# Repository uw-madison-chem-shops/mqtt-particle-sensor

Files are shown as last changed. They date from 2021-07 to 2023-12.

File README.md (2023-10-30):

# MQTT particle sensor

Designed to work with [mqtt.chem.wisc.edu](https://mqtt.chem.wisc.edu/).

## Repository

This is an open source hardware project licensed under the CERN Open Hardware Licence Version 2 - Permissive.
Please see the LICENSE file for the complete license.

## PCB

This PCB was designed using KiCAD version 7.
Refer to `mqtt_particle_sensor.pdf` for schematic.
PCB images generated with [tracespace](https://github.com/tracespace/tracespace) follow.




## Bill of Materials

| reference | value | manufacturer | part number | price | vendors |
| :--- | :--- | :--- | :--- | :---- | :--- |
| C1 | 1u | Multicomp | MC1206B105K500CT  | $0.10 | [Newark](https://www.newark.com/multicomp-pro/mc1206b105k500ct/ceramic-capacitor-1uf-50v-x7r/dp/06R4217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) |
| C2 | 1u |  Multicomp | MC1206B105K500CT  | $0.10 | [Newark](https://www.newark.com/multicomp-pro/mc1206b105k500ct/ceramic-capacitor-1uf-50v-x7r/dp/06R4217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) |
| C3 | 100u | Illinois Capacitor|  107KXM025M| $0.25| [Newark](https://www.newark.com/cornell-dubilier/107kxm025m/aluminum-electrolytic-capacitor/dp/69K8200?ost=107kxm025m) |
| C4 | 10u |  Yageo | CC1206KKX7R8BB106 | $0.25 | [Newark](https://www.newark.com/yageo/cc1206kkx7r8bb106/cap-10uf-25v-mlcc-1206-rohs-compliant/dp/26AK2052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) |
| C5 | 22u | Murata Electronics| GRM31CC71C226ME11L| $0.75 | [Newark](https://www.newark.com/murata/grm31cc71c226me11l/cap-22uf-16v-mlcc-1206-rohs-compliant/dp/64AJ4421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) |
| R1 | 470k | 1206 1/4 1%  | | | |
| R2 | 1M | 1206 1/4 1%  | | | |
| R3 | 1M | 1206 1/4 1%  | | | |
| R4 | 4.7k | 1206 1/4 1%  | | | |
| R5 | 4.7k | 1206 1/4 1%  | | | |
| R6 | 1k | 1206 1/4 1%  | | | |
| R7 | 1k | 1206 1/4 1%  | | | |
| R8 | 4.7k | 1206 1/4 1%  | | | |
| R9 | 4.7k | 1206 1/4 1%  | | | |
| A1 | ESP8266 HUZZAH BREAKOUT BOARD | Adafruit | 2471 |  $10.00 | [Newark](https://www.newark.com/adafruit/2471/adafruit-huzzah-esp8266-breakout/dp/98Y0121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) |
| U1 | Auto Reset Timer | Nexperia  | HEF4060BT,653 | $0.50 |[Newark](https://www.newark.com/nexperia/hef4060bt-653/ic-4000-locmos-smd-4060-soic16/dp/25M9620?st=hef4060bt,653) |
| U2 | ATtiny85 | Microchip Technology| ATTINY85-20PU| $3.00 | [Newark](https://www.newark.com/microchip/attiny85-20pu/microcontroller-mcu-8-bit-attiny/dp/68T3808?ost=attiny85-20pu)|
| U2 | 8pin Dip Socket | Millmax | 110-93-308-41-001000| $1.00 | [Newark](https://www.newark.com/mill-max/110-93-308-41-001000/dip-socket-8-position-through/dp/17C2295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)|
| U3 | HPM Particle Sensor | Honeywell  | 	HPMA115S0-XXX| $63.75 |  [Newark](https://www.newark.com/honeywell/hpma115s0-xxx/particle-sensor-laser-uart-5v/dp/24AC9030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) |
| U3 | Header Connector | Molex | 53047-0810 | $0.14 | [Newark](https://www.newark.com/molex/53047-0810/connector-header-8pos-1row-1-25mm/dp/98K9826?st=53047-0810)|
| U3 | 8pin ribbon cable | Molex | 151340801 | $10.06 | [Newark](https://www.newark.com/molex/15134-0801/cable-assy-8pos-rcpt-rcpt-100mm/dp/01AC7007?ost=151340801)|
| D1 | LED (red) |  Lite-On Inc. | LTST-C230KRKT | $0.25 | [Digikey](https://www.digikey.com/en/products/detail/liteon/LTST-C230KRKT/386857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) |
| D2 | LED (green) |  Lite-On Inc | LTST-C150KGKT| $0.25 | [Digikey](https://www.digikey.com/en/products/detail/liteon/LTST-C150KGKT/365085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) |
| PS1 | Power | CUI | VXO7805-500-M-TR | $3.00 |[Newark](https://www.newark.com/cui/vxo7805-500-m-tr/dc-dc-converter-fixed-5v-rohs/dp/13AJ1536?ost=vxo7805-500-m-tr) |
| J2 | Barrel Jack |CUI |  PJ-002A  | $1.00 | [Digikey](https://www.digikey.com/en/products/detail/cui-devices/PJ-002A/96962) |
| Q1 | 2N7000 | Diodes Inc.  | 2N7002K-7  |$0.25 |[Newark](https://www.newark.com/diodes-inc/2n7002k-7/mosfet-n-channel-60-v-800ma-sot/dp/25R5681?st=2n7002k-7) |
| Q2 | 2N7000 | Diodes Inc.  | 2N7002K-7  |$0.25 |[Newark](https://www.newark.com/diodes-inc/2n7002k-7/mosfet-n-channel-60-v-800ma-sot/dp/25R5681?st=2n7002k-7) |

## Firmware

This project uses [micropython](https://micropython.org/), specifically [microhomie](https://github.com/microhomie/microhomie).
Refer to the "firmware" directory in this repository for detailed instructions.

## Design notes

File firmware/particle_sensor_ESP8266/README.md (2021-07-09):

# mqtt-particle-sensor firmware

This project uses C with [Arduino IDE](https://www.arduino.cc/en/software/) and [micropython](https://micropython.org/), specifically [microhomie](https://github.com/microhomie/microhomie). Currently we build on microhomie-esp8266-v3.0.2, the binary is in the folder.

You must define the private information defined in `settings.py`. Copy `settings.py.example` to make a folder `settings.py` and define all relevant variables.

Run `flash.sh` to flash the board. You will need [esptool](https://github.com/espressif/esptool) and [ampy](https://github.com/scientifichackers/ampy).

We recommend an [FTDI Basic Breakout](https://www.sparkfun.com/products/9716) to physically program the ESP8266.

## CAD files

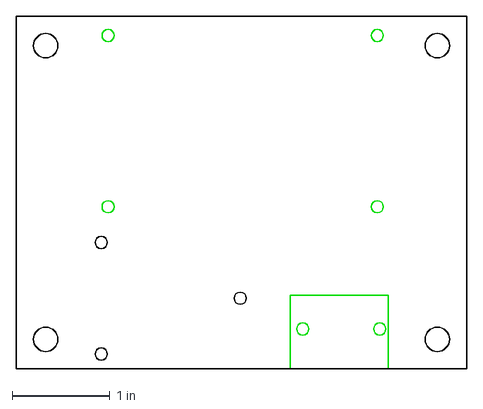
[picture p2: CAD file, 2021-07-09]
mounting-plate/particl-sensor-mounting-plate.dxf
4.60 x 3.60 in

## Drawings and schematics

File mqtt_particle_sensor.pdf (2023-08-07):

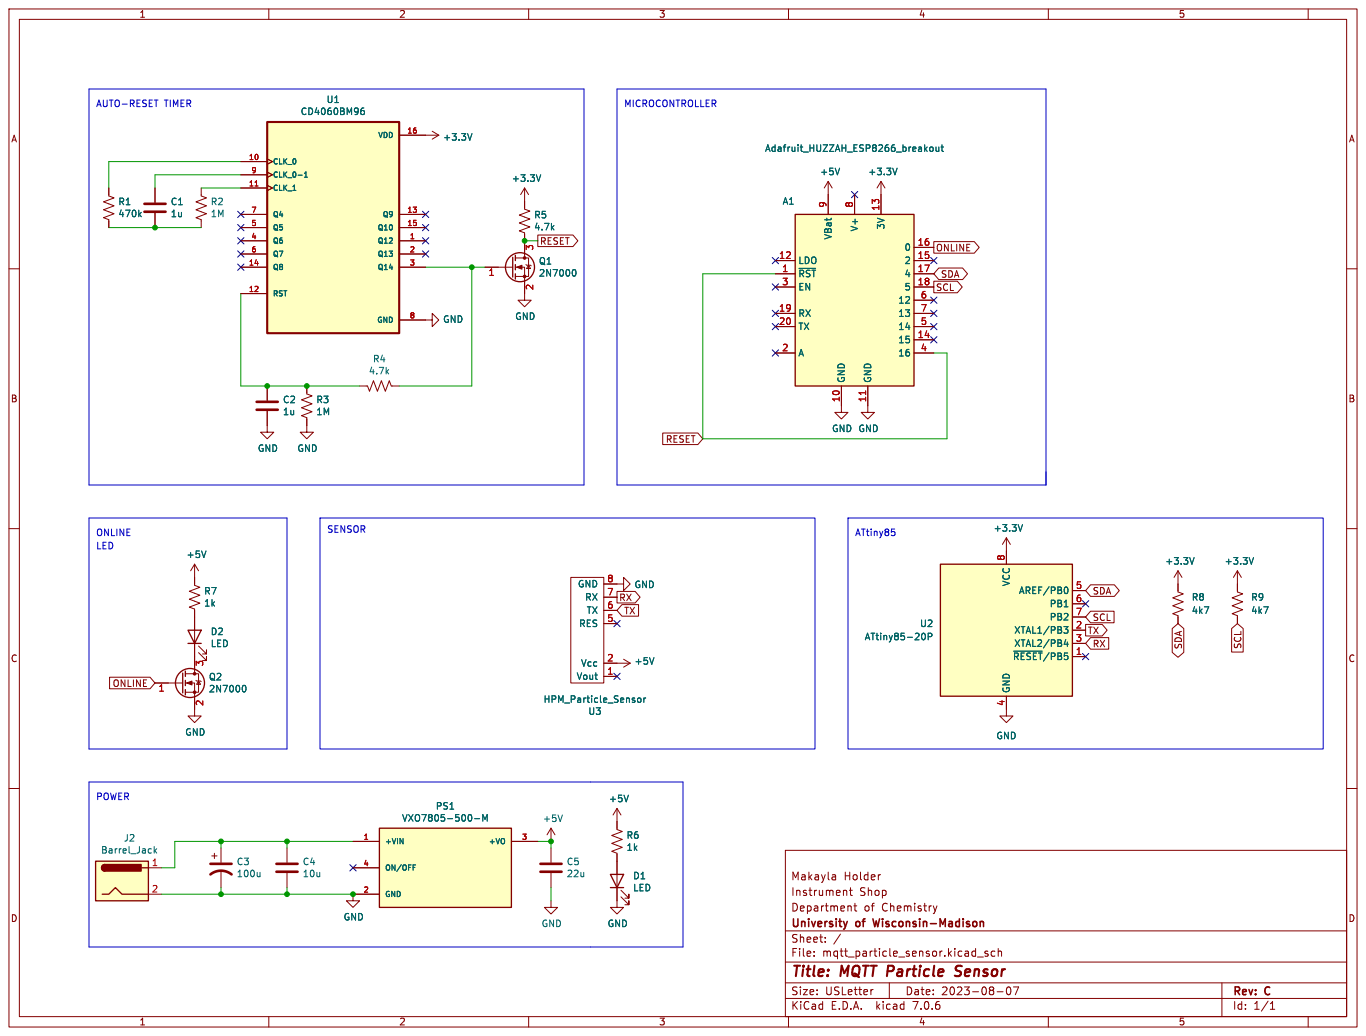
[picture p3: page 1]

Vout 1 Vcc 2 RES 5 TX 6 RX 7 GND 8 U3 HPM_Particle_SensorGND

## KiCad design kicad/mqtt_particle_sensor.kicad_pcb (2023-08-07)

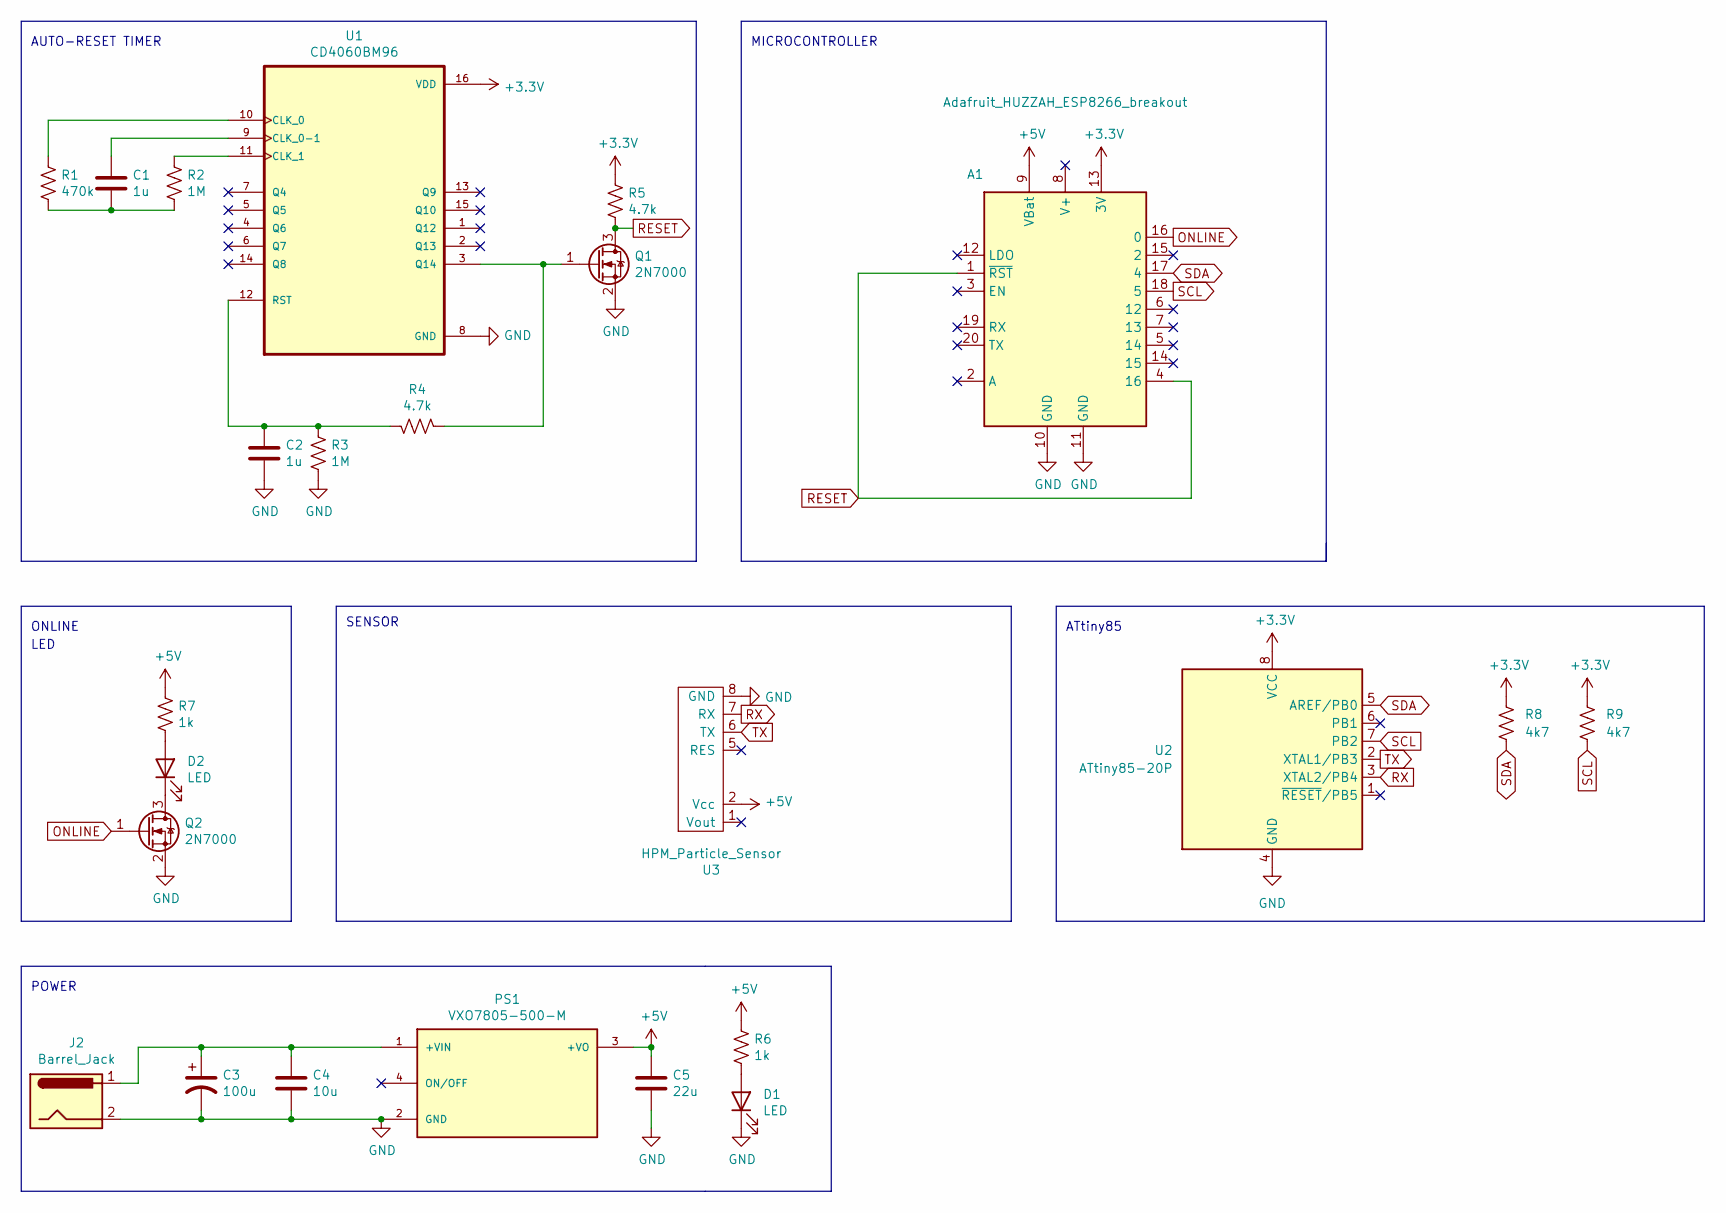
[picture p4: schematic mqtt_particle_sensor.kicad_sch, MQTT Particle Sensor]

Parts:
A1: Adafruit_HUZZAH_ESP8266_breakout
C1, C2: 1u; C_1206_3216Metric_Pad1.33x1.80mm_HandSolder
C3: 100u; CP_Radial_Tantal_D7.0mm_P2.50mm
C4: 10u; C_1206_3216Metric_Pad1.33x1.80mm_HandSolder
C5: 22u; C_1206_3216Metric_Pad1.33x1.80mm_HandSolder
D1, D2: LED; LED_1206_3216Metric_Pad1.42x1.75mm_HandSolder
J2: Barrel_Jack; BarrelJack_Horizontal
PS1: VXO7805-500-M; CONV_VXO7805-500-M
Q1, Q2: 2N7000; SOT-23_Handsoldering
R1: 470k; R_1206_3216Metric_Pad1.30x1.75mm_HandSolder
R2, R3: 1M; R_1206_3216Metric_Pad1.30x1.75mm_HandSolder
R4, R5: 4.7k; R_1206_3216Metric_Pad1.30x1.75mm_HandSolder
R6, R7: 1k; R_1206_3216Metric_Pad1.30x1.75mm_HandSolder
R8, R9: 4k7; R_1206_3216Metric_Pad1.30x1.75mm_HandSolder
U1: CD4060BM96; SOIC-16_3.9x9.9mm_P1.27mm
U2: ATtiny85-20P; DIP-8_W7.62mm
U3: HPM_Particle_Sensor; honewell-hpm

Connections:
+3V3: A1.13 (3V), R5.1, R8.1, R9.1, U1.16 (VDD), U2.8 (VCC)
+5V: A1.9 (VBat), C5.1, PS1.3 (+VO), R6.1, R7.1, U3.2 (Vcc)
GND: A1.10 (GND), A1.11 (GND), C2.2, C3.2, C4.2, C5.2, D1.1 (K), J2.2, PS1.2 (GND), Q1.2 (S), Q2.2 (S), R3.2, U1.8 (GND), U2.4 (GND), U3.8 (GND)
unnamed: C1.2, R1.1, R2.1
unnamed: D1.2 (A), R6.2
unnamed: D2.2 (A), R7.2
unnamed: D2.1 (K), Q2.3 (D)
unnamed: C3.1, C4.1, J2.1, PS1.1 (+VIN)
unnamed: Q1.1 (G), R4.1, U1.3 (Q14)
unnamed: R1.2, U1.10 (CLK_0)
unnamed: C1.1, U1.9 (CLK_0-1)
unnamed: R2.2, U1.11 (CLK_1)
unnamed: C2.1, R3.1, R4.2, U1.12 (RST)
ONLINE: A1.16 (0), Q2.1 (G)
RESET: A1.1 (~RST), A1.4 (16), Q1.3 (D), R5.2
RX: U2.3 (XTAL2/PB4), U3.7 (RX)
SCL: A1.18 (5), R9.2, U2.7 (PB2)
SDA: A1.17 (4), R8.2, U2.5 (AREF/PB0)
TX: U2.2 (XTAL1/PB3), U3.6 (TX)

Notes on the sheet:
AUTO-RESET TIMER
MICROCONTROLLER
LED
POWER
ATtiny85
ONLINE
SENSOR

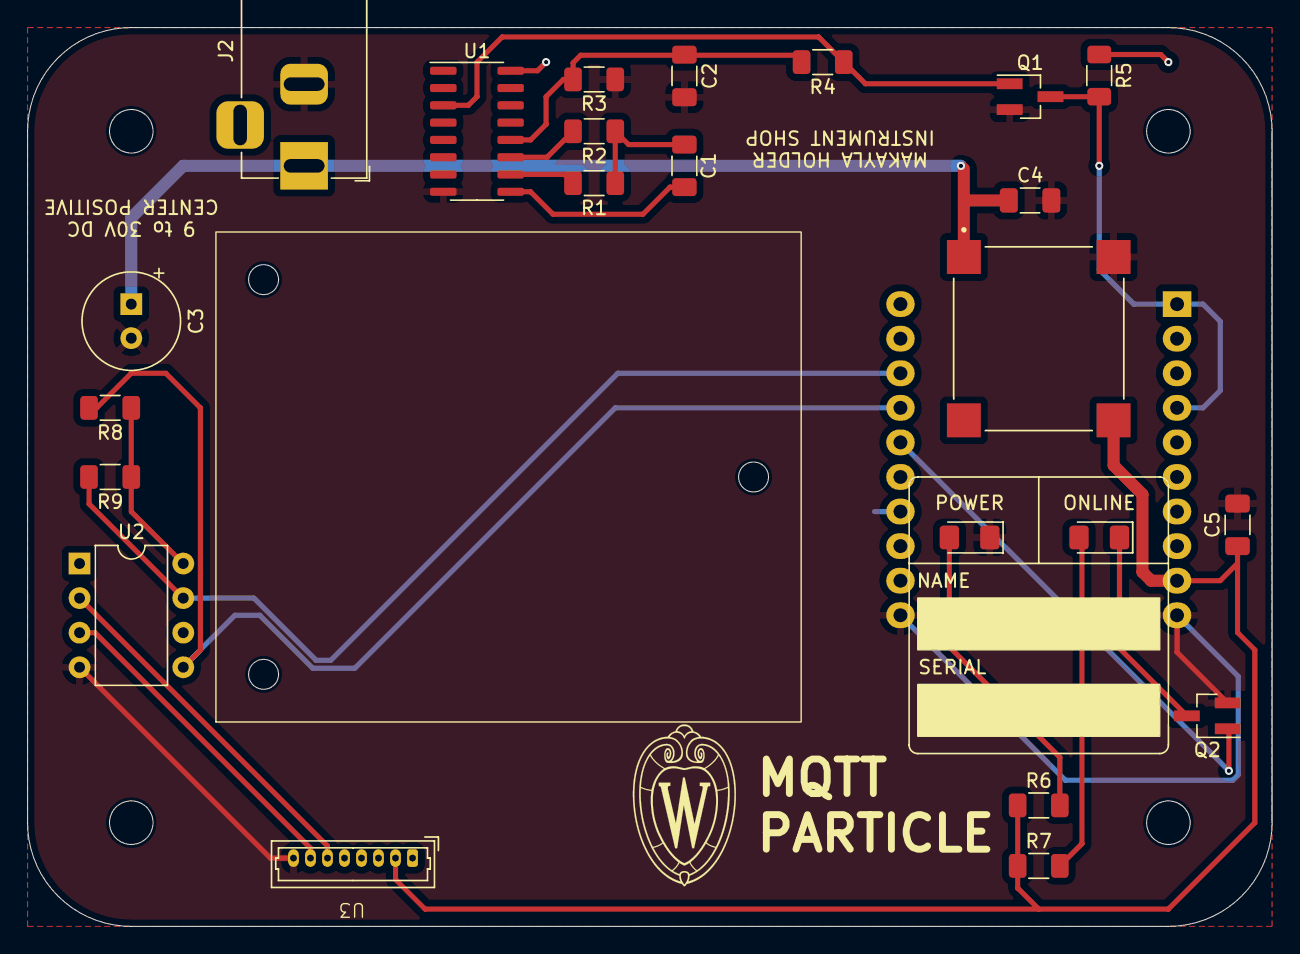
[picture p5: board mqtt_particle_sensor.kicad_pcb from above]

Board: 2 copper layers, 91.4 x 66.0 mm, 24 parts (1 on the bottom side), 19 nets.

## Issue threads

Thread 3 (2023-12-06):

add ATtiny85 reset connection

untzag, 2023-12-06:
Find that the ATtiny gets caught in a bad state periodically, needed to add a jumper to revision C so that the ESP could periodically reset the tiny. Should add a trace in next version.

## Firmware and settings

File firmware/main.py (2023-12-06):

import settings

import sys
import machine
from machine import Pin, I2C, SPI
import network
import time
import struct

import mqtt_as
mqtt_as.MQTT_base.DEBUG = True



from homie.constants import FALSE, TRUE, BOOLEAN, FLOAT, STRING
from homie.device import HomieDevice
from homie.node import HomieNode
from homie.property import HomieNodeProperty

from uasyncio import get_event_loop, sleep_ms


from hpm import Sensor


class ParticleSensor(HomieNode):

    def __init__(self, name="hpm", device=None):
        super().__init__(id="hpm", name=name, type="sensor")
        self.device = device
        self.sensor = Sensor()
        self.pm25 = HomieNodeProperty(
            id="pm25",
            name="pm25",
            unit="ppm",
            settable=False,
            datatype=FLOAT,
            default=0,
        )
        self.add_property(self.pm25)
        self.pm10 = HomieNodeProperty(
            id="pm10",
            name="pm10",
            unit="ppm",
            settable=False,
            datatype=FLOAT,
            default=0,
        )
        self.add_property(self.pm10)
        self.uptime = HomieNodeProperty(
            id="uptime",
            name="uptime",
            settable=False,
            datatype=STRING,
            default="PT0S"
        )
        self.add_property(self.uptime)
        self.ip = HomieNodeProperty(
            id="ip",
            name="ip",
            settable=False,
            datatype=STRING,
            default="",
        )
        self.add_property(self.ip)
        self.led = Pin(0, Pin.OUT)
        self.online_led = Pin(15, Pin.OUT)
        self.online_led.off()
        self.tiny_reset = Pin(2, Pin.OUT)
        self.tiny_reset.on()
        self.last_online = time.time()
        self.start = time.time()
        loop = get_event_loop()
        loop.create_task(self.update_data())

    async def update_data(self):
        # wait until connected
        for _ in range(60):
            await sleep_ms(1_000)
            if self.device.mqtt.isconnected():
                break
        # loop forever
        while True:
            while self.device.mqtt.isconnected():
                print("hello world")
                self.last_online = time.time()
                self.online_led.on()
                self.led.value(0)  # illuminate onboard LED
                try:
                    measured = self.sensor.read()
                except OSError:
                    print("oserror")
                    await sleep_ms(1000)
                    continue
                self.pm25.data = str(measured["pm25"])
                self.pm10.data = str(measured["pm10"])
                self.uptime.data = self.get_uptime()
                self.ip.data = network.WLAN().ifconfig()[0]
                self.led.value(1)  # onboard LED off
                print("resetting tiny")
                self.tiny_reset.off()  # low resets tiny
                await sleep_ms(100)
                self.tiny_reset.on()
                await sleep_ms(15_000)
            while not self.device.mqtt.isconnected():
                if time.time() - self.last_online > 300:   # 5 minutes
                    machine.reset()
                self.online_led.off()
                self.led.value(0)  # illuminate onboard LED
                await sleep_ms(100)
                self.led.value(1)  # onboard LED off
                await sleep_ms(1000)
            machine.reset()  # if lost connection, restart

    def get_uptime(self):
        diff = int(time.time() - self.start)
        out = "PT"
        # hours
        if diff // 3600:
            out += str(diff // 3600) + "H"
            diff %= 3600
        # minutes
        if diff // 60:
            out += str(diff // 60) + "M"
            diff %= 60
        # seconds
        out += str(diff) + "S"
        return out


def main():
    homie = HomieDevice(settings)
    homie.add_node(ParticleSensor(device=homie))
    homie.run_forever()


if __name__ == "__main__":
    main()

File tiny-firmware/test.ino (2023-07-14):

#include <SoftwareSerial.h>
#include "./TinyWireS.h"

#define I2C_SLAVE_ADDRESS 0x10
SoftwareSerial mySerial(3, 4);  //rx, tx
char sensor_output[32];
char i2c_output[4];
unsigned int pm25;
unsigned int pm10;

int index = 0;

void setup() {
  // i2c
  TinyWireS.begin(I2C_SLAVE_ADDRESS);
  TinyWireS.onRequest(requestEvent);
  // uart
  pinMode(3, INPUT);
  pinMode(4, OUTPUT);
  mySerial.begin(9600);
  delay(500);
  mySerial.write(0x68014057);  // ask the sensor to send data asyncronously
  // LED
  pinMode(1, OUTPUT);
}

void loop() {

  TinyWireS_stop_check();  // need to call periodically

  if (mySerial.available()) {
    // brute force shift all data to left one char
    for (int i = 0; i < 32; i++) {
      sensor_output[i] = sensor_output[i + 1];
    }
    // place new byte on trailing end of buffer
    sensor_output[31] = mySerial.read();
  }

  if ((sensor_output[0] == 0x42) & (sensor_output[1] == 0x4d)) {
    digitalWrite(1, HIGH);
    i2c_output[0] = sensor_output[6];
    i2c_output[1] = sensor_output[7];
    i2c_output[2] = sensor_output[8];
    i2c_output[3] = sensor_output[9];
    delay(500);
    digitalWrite(1, LOW);
  }
}

void requestEvent() {
  for (int i = 0; i < 4; i++) {
    TinyWireS.send(i2c_output[i]);
  }
}

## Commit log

2021-07-09 Added all current files for mqtt-particle-sensor
    [mqtt_particle_sensor.kicad_pcb, mqtt_particle_sensor.sch, particl-sensor-mounting-plate.dxf]
2023-09-18 Update README.md
    Added Bill of Materials for revision C of the mqtt particle sensor
2023-09-18 Update README.md
    Updated Bill of Materials to include more parts that were not accounted for
2023-10-30 hpm i2c
